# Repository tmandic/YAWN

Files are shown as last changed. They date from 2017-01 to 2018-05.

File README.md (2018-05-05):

# YAWN - Your Autonomous Wireless Node
This repository presents the developed hardware and software for wireless node based on PIC16LF1459. The repository includes schematic and gerber files. Furthermore, the software libraries are added for basic node functionality.

# Hardware description
uC: PIC16LF1459 low power microcontroller programmable through header U4 (pins 11-15)

communication modules: nRF24L01+ (SPI) or BLE HM-11 (UART)

sensors: HDC1080 (temperature and humidity sensor) and OPT3001 (light sensor)

power supply: 1.5 F supercapacitor or CR2032 battery. The supercapacictor can be charged through USB port, or through expansions header (i.e. energy harvesting module aka shield, connected to YAWN)

LED: two green and red signalling LED 

push buttons: 4 general purpose push buttons and RESET button

timer: for long interval and minmum sleep current consumption

jumpers: J1-J4 push buttons select jumpers, J5-J6 power supply configuration, J7-J8 DONE pin (timer is used) selector, J11 - VCAP monitor, all other jumpers are header pin selectors

(c) University of Zagreb Faculty of Electrical Engineering and Computing

_Authors : T. Mandic, N. Budimir, A. Baric

_Version : 5

_Date : 2018/05/05

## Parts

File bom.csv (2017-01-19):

Reference | Value | Footprint | Datasheet | Farnell | Q10+ (GBP) | Comment
C9 | 1.5F | komponente:CAP&BAT |  | 2472074+2115303 | 2.78+0.683
U7 | OPT3001 | komponente:USON-6 |  | 2466963 | 2.46
L1 | BLM21 | komponente:0805 |  | 1515661 | 0.0536
U1 | USB | komponente:USBMICRO |  | 2293755 | 0.522
C12 | 220nF | komponente:0805 |  | 2074517 | 0.0281
R6 | 15 | komponente:0805 |  | 2447576 | 0.005
C6 | 10uF | komponente:0805 |  | 2320833 | 0.15
SW4 | C | komponente:SPST |  | 1555987 | 0.0766
SW5 | D | komponente:SPST |  | 1555987 | 0.0766
SW2 | A | komponente:SPST |  | 1555987 | 0.0766
U5 | BLE-HM11 | komponente:HM-11 |  | ebay | 7.3
R10 | 820R | komponente:0805 |  | 2074517 | 0.0281
D1 | redled | komponente:PLCC2 |  | 1328348 | 0.238
D2 | greenled | komponente:PLCC2 |  | 1659076 | 0.257
SW3 | B | komponente:SPST |  | 1555987 | 0.0766
U6 | HDC1080 | komponente:PWSON-N6 |  | 2535017 | 4.13
R17 | 10k | komponente:0805 |  | 9332391 | 0.0018
Y1 | 12 MHz | komponente:HC49-US |  | 2467681 | 0.305
C10 | 18pF | komponente:0805 |  | 2497020 | 0.0293
C11 | 18pF | komponente:0805 |  | 2497020 | 0.0293
R9 | 820R | komponente:0805 |  | 2074517 | 0.0281
R1 | 47k | komponente:0805 |  | 1469929 | 0.0164
R2 | 47k | komponente:0805 |  | 1469929 | 0.0164
R3 | 47k | komponente:0805 |  | 1469929 | 0.0164
R5 | 47k | komponente:0805 |  | 1469929 | 0.0164
SW1 | RESET | komponente:RESET |  | 2456210 | 0.172
R4 | 220k | komponente:0805 |  | 9234292 | 0.013
R14 | 47k | komponente:0805 |  | 1469929 | 0.0164
R12 | 10k | komponente:0805 |  | 9332391 | 0.0018
R13 | 10k | komponente:0805 |  | 9332391 | 0.0018
U9 | TPL5110 | komponente:SOT-23-6 |  | 2471145 | 0.832
VR2 | VR | komponente:0805 |  | 8832463 | 0.502
VR1 | VR | komponente:0805 |  | 8832463 | 0.502
U3 | PIC16(L)F1459 | komponente:SSOP-20 |  | 2305825 | 1.20
R18 | R | komponente:0805
Q2 | FDC6312P | komponente:SSOT-6 |  | 1700713 | 0.0958
R19 | DNP | komponente:0805
R20 | R | komponente:0805
C13 | 1uF | komponente:0805 |  | 2112709 | 0.41
C15 | 100nF | komponente:0805 |  | 1759167 | 0.0115
C16 | 10uF | komponente:0805 |  | 2320833 | 0.15
J2 | JUMPER | komponente:J1x04
J1 | JUMPER | komponente:J1x04
J4 | JUMPER | komponente:J1x04
J3 | JUMPER | komponente:J1x04
J6 | JUMPER | komponente:J1x04
J5 | JUMPER | komponente:J1x04
J10 | JUMPER | komponente:J1x04
J9 | JUMPER | komponente:J1x04
J11 | JUMPER | komponente:J1x04
J8 | JUMPER | komponente:J1x04
J7 | JUMPER | komponente:J1x04
J13 | JUMPER | komponente:J1x04
J12 | JUMPER | komponente:J1x04
U4 | 2x10pin_header | komponente:HEADER |  | 1667516 | 2.04 | 2x (price doubled)
U8 | NRF24L01+ | komponente:NRF24L01+-mini |  | ebay | 0.9
J15 | JUMPER | komponente:J1x04
J14 | JUMPER | komponente:J1x04
J16 | JUMPER | komponente:J1x04
J17 | JUMPER | komponente:J1x04
R7 | 360 | komponente:0805 |  | 2323839 | 0.013
D4 | DA3X101K0L | komponente:SOT-23 |  | 2284128 | 0.0293
R8 | 220 | komponente:0805 |  | 9332804 | 0.0018
D3 | BAT54W | komponente:SOT-323D |  | 1081197 | 0.17
R11 | 220 | komponente:0805 |  | 9332804 | 0.0018
C4 | 100nF | komponente:0805 |  | 1759167 | 0.0115
C1 | 100nF | komponente:0805 |  | 1759167 | 0.0115
C2 | 100nF | komponente:0805 |  | 1759167 | 0.0115
C5 | 100nF | komponente:0805 |  | 1759167 | 0.0115
C3 | 100nF | komponente:0805 |  | 1759167 | 0.0115
C7 | 100nF | komponente:0805 |  | 1759167 | 0.0115
C14 | 100nF | komponente:0805 |  | 1759167 | 0.0115

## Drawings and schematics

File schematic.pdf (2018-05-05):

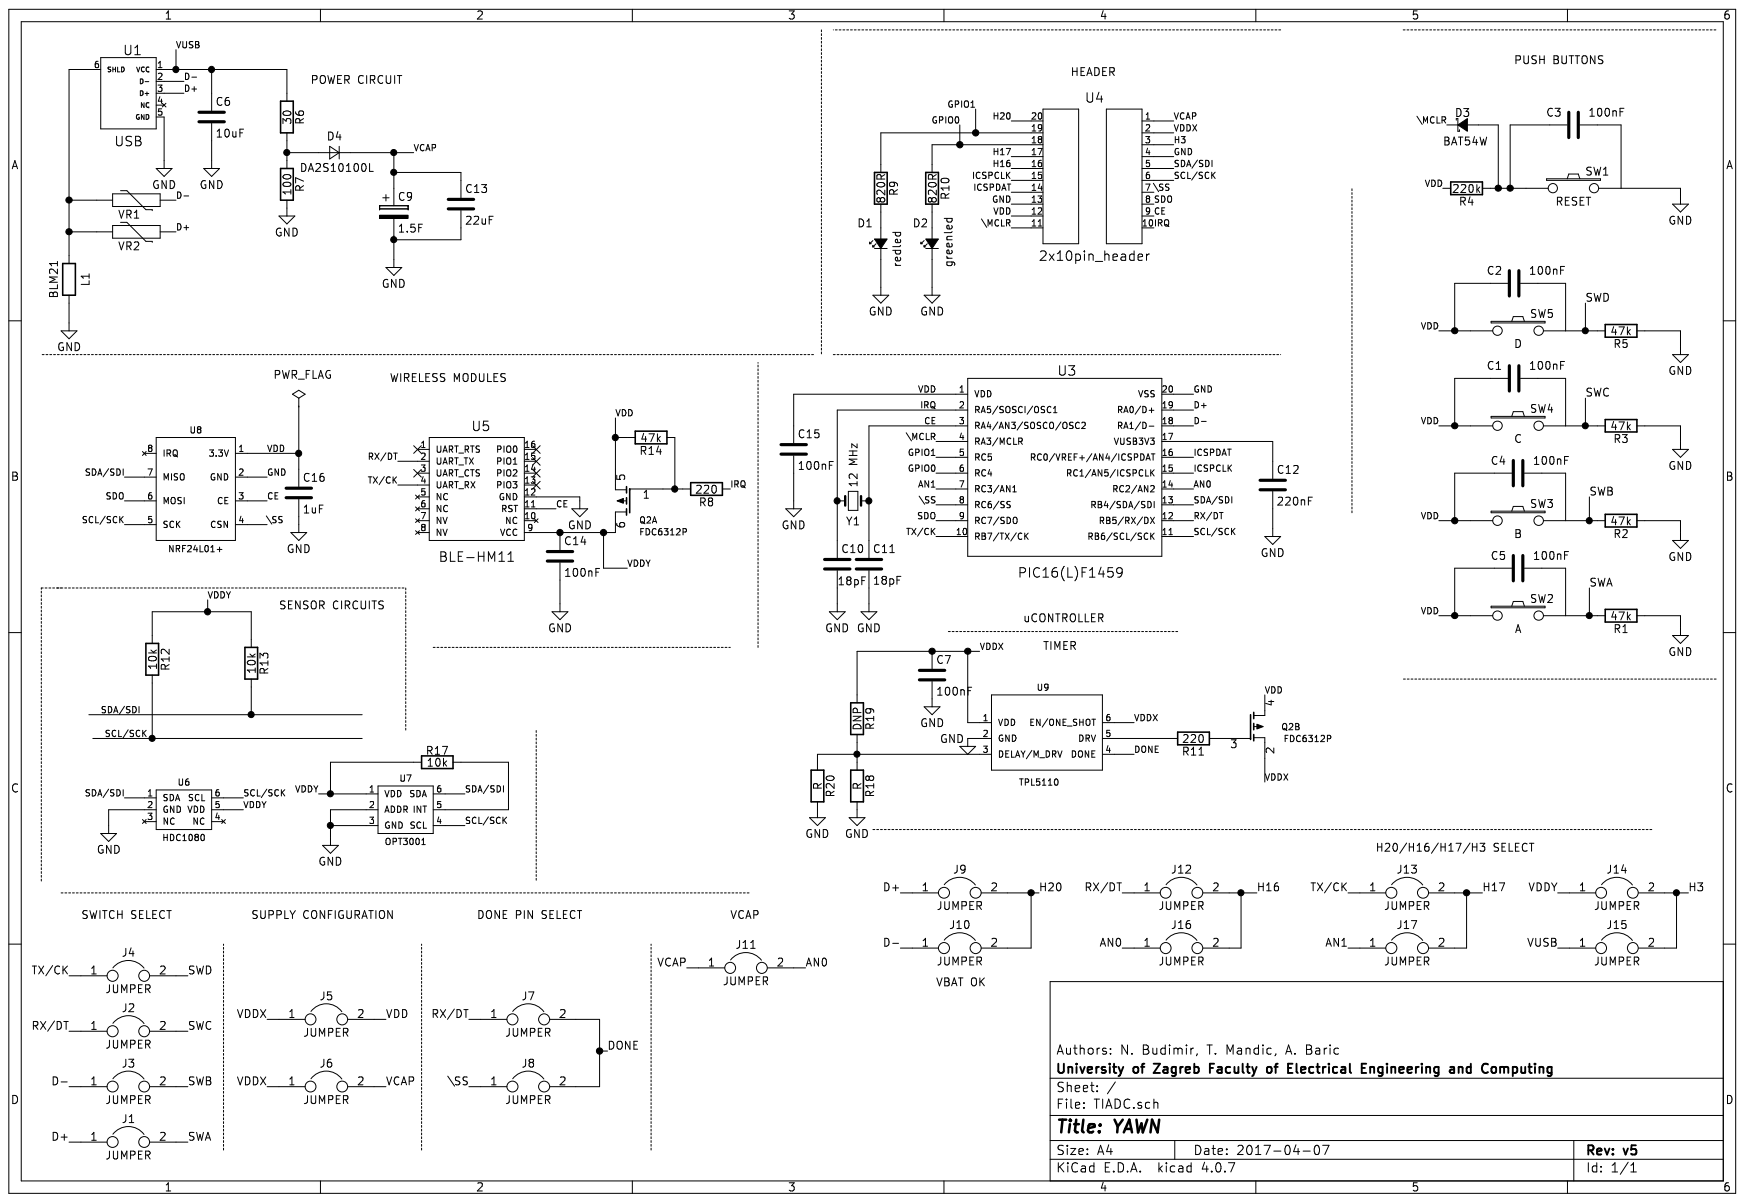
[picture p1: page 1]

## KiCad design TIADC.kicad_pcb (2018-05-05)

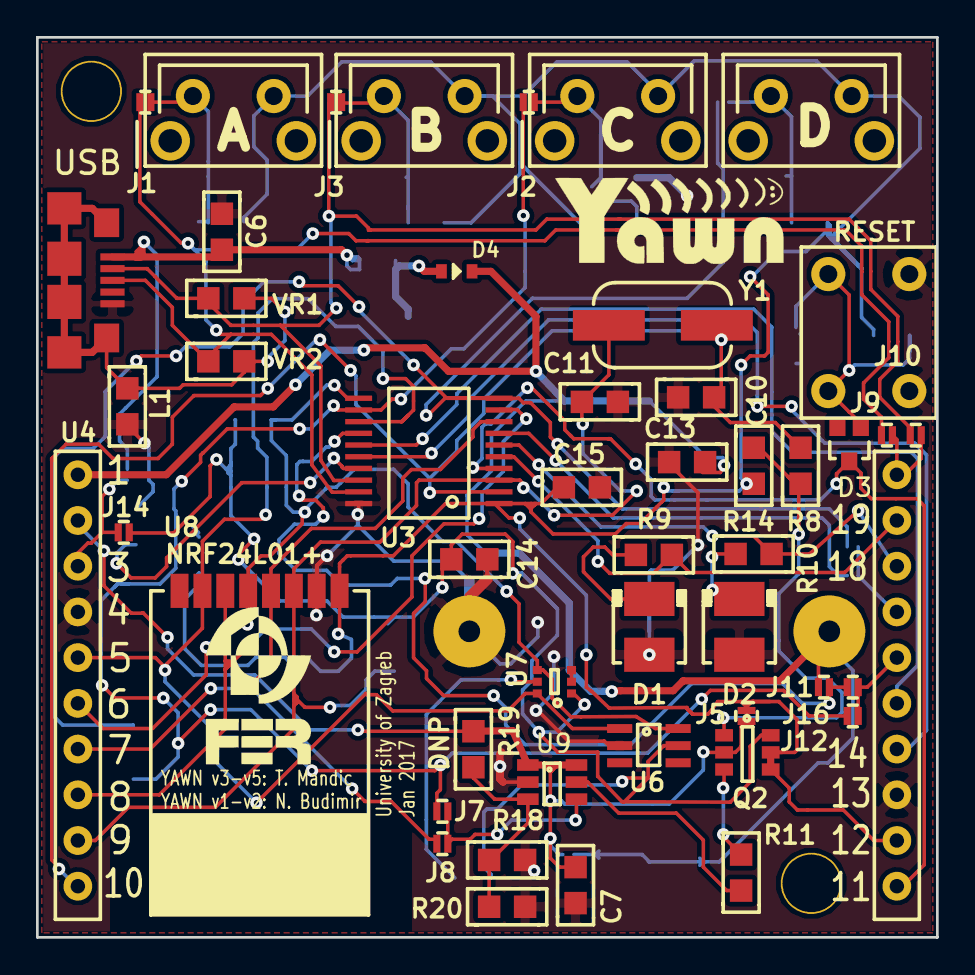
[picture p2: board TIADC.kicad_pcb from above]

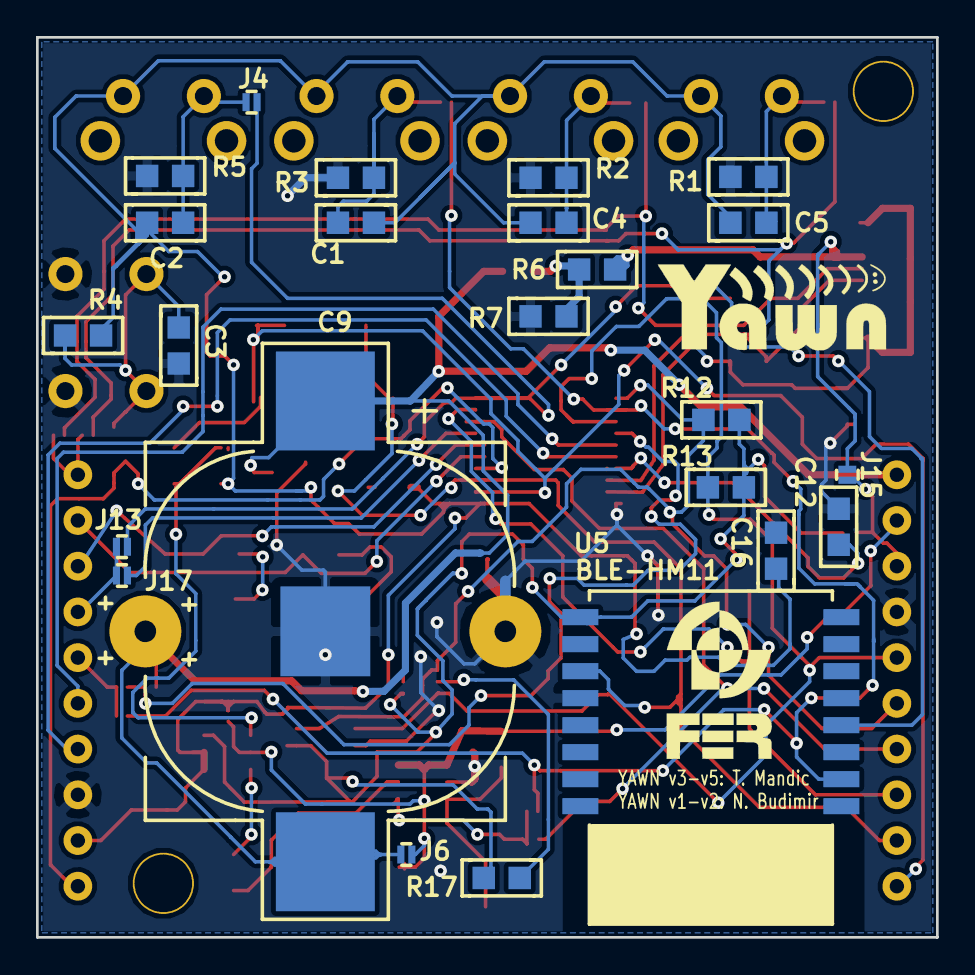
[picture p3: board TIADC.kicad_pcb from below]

Board: 2 copper layers, 50.0 x 50.0 mm, 72 parts (24 on the bottom side), 43 nets.

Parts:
C1, C2, C3, C4, C5, C7, C14, C15: 100nF; 0805
C6: 10uF; 0805
C9: 1.5F; CAP&BAT
C10, C11: 18pF; 0805
C12: 220nF; 0805
C13: 22uF; 0805
C16: 1uF; 0805
D1: redled; PLCC2
D2: greenled; PLCC2
D3: BAT54W; SOT-323D
D4: DA2S10100L; SOD-523
J1, J2, J3, J4, J5, J6, J7, J8, J9, J10, J11, J12, J13, J14, J15, J16, J17: JUMPER; J1x04
L1: BLM21; 0805
Q2: FDC6312P; SSOT-6
R1, R2, R3, R5, R14: 47k; 0805
R4: 220k; 0805
R6: 30; 0805
R7: 100; 0805
R8, R11: 220; 0805
R9, R10: 820R; 0805
R12, R13, R17: 10k; 0805
R18, R20: R; 0805
R19: DNP; 0805
SW1: RESET
SW2: A; SPST
SW3: B; SPST
SW4: C; SPST
SW5: D; SPST
U1: USB; USBMICRO
U3: PIC16(L)F1459; SSOP-20
U4: 2x10pin_header; HEADER
U5: BLE-HM11; HM-11
U6: HDC1080; PWSON-N6
U7: OPT3001; USON-6
U8: NRF24L01+; NRF24L01+-mini
U9: TPL5110; SOT-23-6
VR1, VR2: VR; 0805
Y1: 12 MHz; HC49-US

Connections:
/AN0: J11.2, J16.1, U3.14
/AN1: J17.1, U3.7
/CE: C11.1, U3.3, U4.9, U5.11, U8.3, Y1.2
/D+: J1.1, J9.1, U1.3, U3.19, VR2.1
/D-: J3.1, J10.1, U1.2, U3.18, VR1.1
/DONE: J7.2, J8.2, U9.4
/GPIO0: R10.1, U3.6, U4.18
/GPIO1: R9.1, U3.5, U4.19
/H3: J14.2, J15.2, U4.3
/H16: J12.2, J16.2, U4.16
/H17: J13.2, J17.2, U4.17
/H20: J9.2, J10.2, U4.20
/ICSPCLK: U3.15, U4.15
/ICSPDAT: U3.16, U4.14
/IRQ: C10.1, R8.1, U3.2, U4.10, Y1.1
/RX/DT: J2.1, J7.1, J12.1, U3.12, U5.2
/SCL/SCK: R12.2, U3.11, U4.6, U6.6, U7.4, U8.5
/SDA/SDI: R13.2, U3.13, U4.5, U6.1, U7.6, U8.7
/SDO: U3.9, U4.8, U8.6
/SWA: C5.2, J1.2, R1.2, SW2.2
/SWB: C4.2, J3.2, R2.2, SW3.2
/SWC: C1.2, J2.2, R3.2, SW4.2
/SWD: C2.2, J4.2, R5.2, SW5.2
/TX/CK: J4.1, J13.1, U3.10, U5.4
/VCAP: C9.1, C13.1, D4.1, J6.2, J11.1, U4.1
/VDD: C1.1, C2.1, C4.1, C5.1, C15.1, C16.1, J5.2, Q2.4, Q2.5, R4.2, R14.2, SW2.1, SW3.1, SW4.1, SW5.1, U3.1, U4.12, U8.1
/VDDX: C7.1, J5.1, J6.1, Q2.2, R19.1, U4.2, U9.1, U9.6
/VDDY: C14.1, J14.1, Q2.6, R12.1, R13.1, R17.2, U5.9, U6.5, U7.1
/VUSB: C6.1, J15.1, R6.1, U1.1
/\MCLR: D3.3, U3.4, U4.11
/\SS: J8.1, U3.8, U4.7, U8.4
GND: C3.2, C6.2, C7.2, C9.2, C10.2, C11.2, C12.2, C13.2, C14.2, C15.2, C16.2, D1.1, D2.1, L1.2, R1.1, R2.1, R3.1, R5.1, R7.2, R18.2, R20.2, SW1.2, U1.5, U3.20, U4.4, U4.13, U5.12, U6.2, U7.2, U7.3, U8.2, U9.2
unnamed: C3.1, D3.1, R4.1, SW1.1
unnamed: C12.1, U3.17
unnamed: D1.2, R9.2
unnamed: D2.2, R10.2
unnamed: D4.2, R6.2, R7.1
unnamed: L1.1, U1.6, VR1.2, VR2.2
unnamed: Q2.1, R8.2, R14.1
unnamed: Q2.3, R11.1
unnamed: R11.2, U9.5
unnamed: R17.1, U7.5
unnamed: R18.1, R19.2, R20.1, U9.3

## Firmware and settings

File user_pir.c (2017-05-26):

/******************************************************************************/
/* Files to Include                                                           */
/******************************************************************************/

#if defined(__XC)
    #include <xc.h>         /* XC8 General Include File */
#elif defined(HI_TECH_C)
    #include <htc.h>        /* HiTech General Include File */
#endif

#include <stdint.h>         /* For uint8_t definition */
#include <stdbool.h>        /* For true/false definition */

#include "user.h"

/******************************************************************************/
/* User Functions                                                             */
/******************************************************************************/

void InitApp(void)
{

   //disable analog functions
   ANSELA = 0x00;
   ANSELB = 0x00;
   ANSELC = 0x00;

   TRISCbits.TRISC0 = 0; //ICSPDAT output
   TRISCbits.TRISC1 = 0; //ICSPCLK output
   TRISCbits.TRISC2 = 0; //AN0 output
   TRISCbits.TRISC3 = 0; //AN1 output
   TRISCbits.TRISC4 = 0; //Green led output
   TRISCbits.TRISC5 = 0; //Red led output
   TRISCbits.TRISC6 = 0; //CSN output
   TRISCbits.TRISC7 = 0; //SDO output

   TRISAbits.TRISA4 = 0; //CE output
   TRISAbits.TRISA5 = 0; //IRQ output

   TRISBbits.TRISB4 = 1; //SDI input
   TRISBbits.TRISB5 = 1; //IOC input
   TRISBbits.TRISB6 = 0; //clock output
   TRISBbits.TRISB7 = 1; //IOC input

   LATCbits.LATC0 = 0;
   LATCbits.LATC1 = 0;
   LATCbits.LATC2 = 0;
   LATCbits.LATC3 = 0;
   LATCbits.LATC4 = 0;
   LATCbits.LATC5 = 0;
   LATCbits.LATC6 = 0;
   LATCbits.LATC7 = 0;

   LATAbits.LATA4 = 0;
   LATAbits.LATA5 = 0;

   LATBbits.LATB6 = 0;

}
